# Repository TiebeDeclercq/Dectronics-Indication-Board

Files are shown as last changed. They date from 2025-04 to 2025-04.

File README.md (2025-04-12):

# DECTRONICS INDICATION BOARD

The LED PCB is a versatile lighting interface board designed to connect standard LEDs and addressable WS2812B RGB LEDs to systems via FCP connectors or pin headers. It provides flexible soldering options to choose which connection option you want to use.
## Overview

This PCB serves as a lighting expansion board that can be integrated with various systems through standardized connectors. It features both power indicator LEDs and a chain of WS2812B addressable RGB LEDs, making it suitable for status indication, ambient lighting, and visual feedback in electronic projects.

## Features

- **Power/Status LEDs**: 4 individual LEDs with current-limiting resistors
- **WS2812B Support**: Chain of 6 addressable RGB LEDs
- **Dual FCP Connectors**: Front and back connection options
- **Header Connectors**: Standard 2.54mm pin headers for breadboard compatibility
- **Flexible Soldering**: Multiple connection points for different configurations
- **Mounting Holes**: Two mounting holes for secure installation
## Hardware Schematic
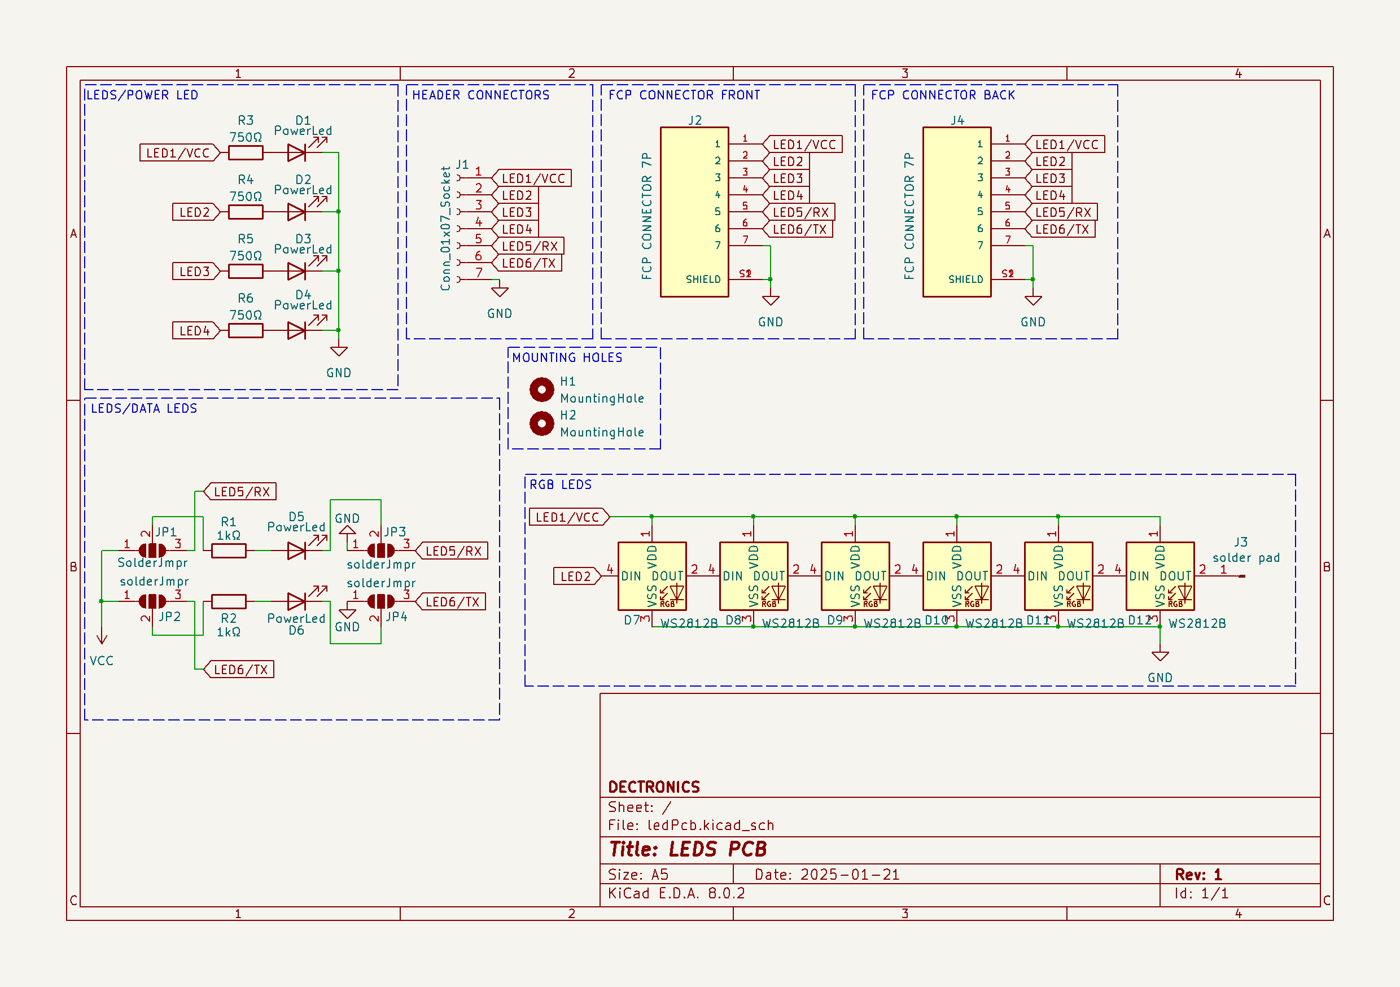
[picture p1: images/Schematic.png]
Indication board Schematic

## Assembled PCB
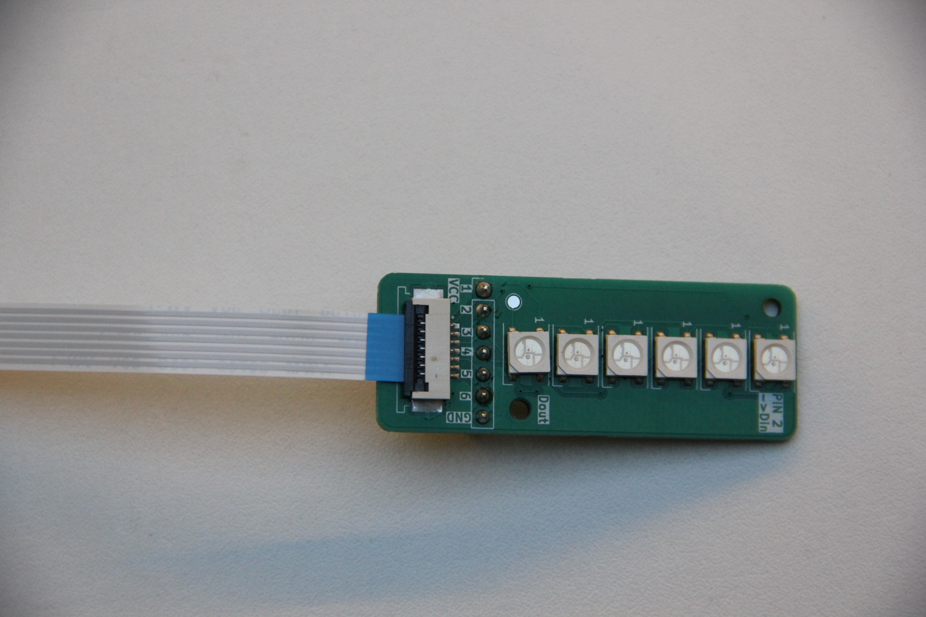
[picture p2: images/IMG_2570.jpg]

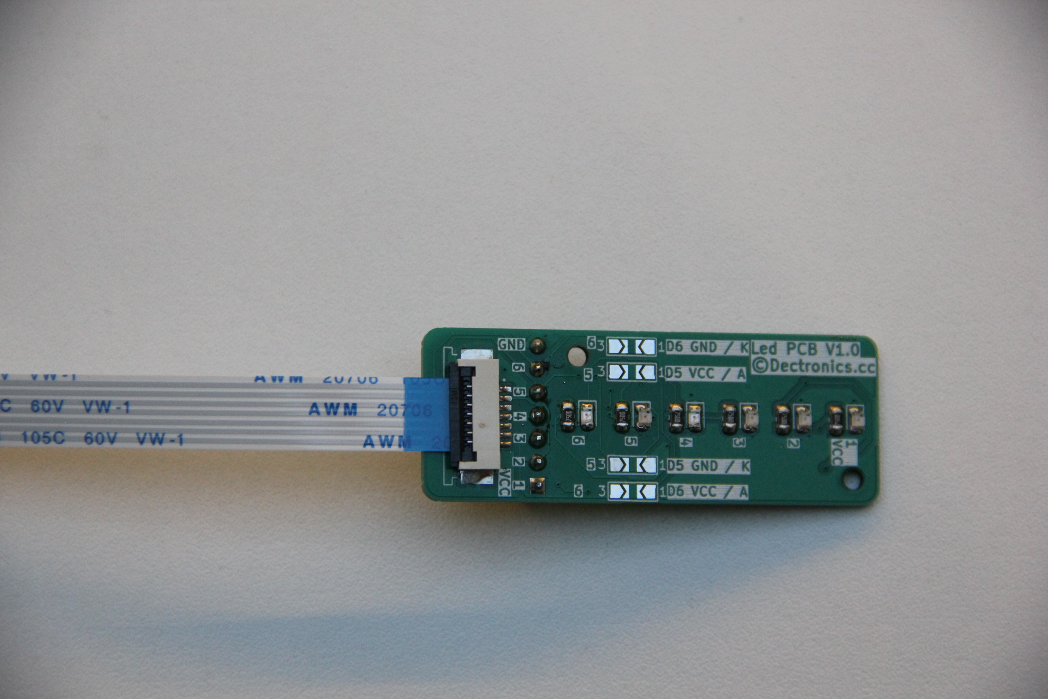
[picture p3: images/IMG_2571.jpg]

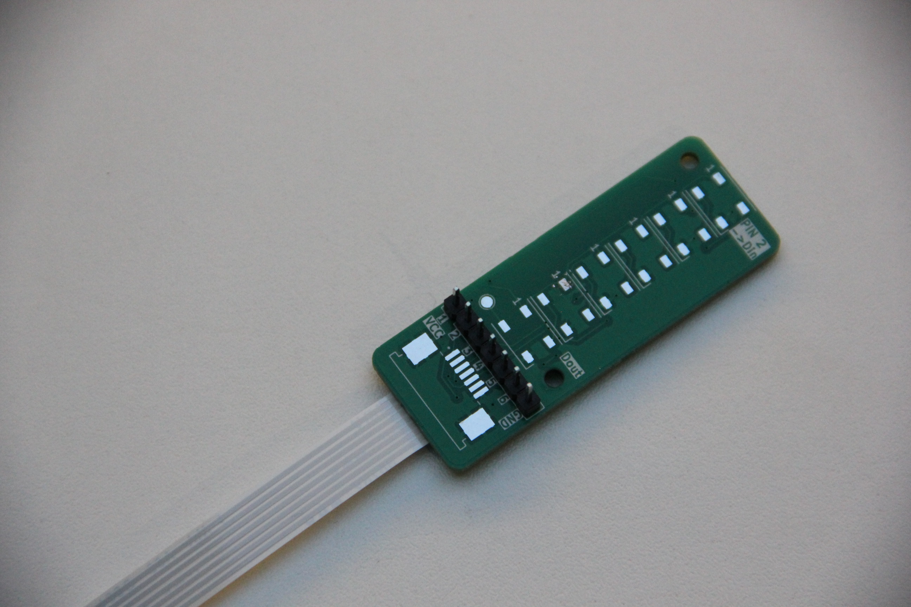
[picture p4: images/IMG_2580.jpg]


## Connector Pinout
### FCP Connector (J2/J4)

| Pin | Function |
| --- | --- |
| 1 | LED1/VCC |
| 2 | LED2 |
| 3 | LED3 |
| 4 | LED4 |
| 5 | LED5/RX  |
| 6 | LED6/TX  |
| 7 | GND |

### Header Connector (J1)

|Pin|Function|
|---|---|
|1|LED1/VCC|
|2|LED2|
|3|LED3|
|4|LED4|
|5|LED5/RX|
|6|LED6/TX|
|7|GND|

## Soldering Options

The PCB includes multiple solder jumpers (JP1-JP4) that allow you to configure the connections based on your specific requirements:

- **JP1/JP3**: Via these jumpers you can configure if you want to use it as an adressable led or to see the rx progress on the led
- **JP2/JP4**: Via these jumpers you can configure if you want to use it as an adressable led or to see the tx progress on the led

### Soldering Configurations:

You can choose to solder different components depending on your needs:

1. **Status LEDS**: Solder R3-R6 and D1-D4 for basic power/status indication
2. **RGB LEDS**: Solder the WS2812B LEDs (D7-D12) and appropriate jumpers
## Mounting

The PCB includes two mounting holes (H1 and H2) for secure installation using M3 screws.

## Usage Examples

### Status Indication

Use the individual LEDs (D1-D4) to indicate system status, power levels, or operational modes.

### Ambient Lighting

Program the WS2812B LEDs for decorative lighting effects, color-coded status information, or animations.

### Visual Feedback

Create visual feedback systems using the addressable RGB LEDs to indicate process states, alert conditions, or data visualization.
## Compatibility

This LED PCB is designed to work with:

- Systems using FCP connector standard
- Breadboard-compatible systems via pin headers
- Any microcontroller capable of driving WS2812B LEDs

© DECTRONICS

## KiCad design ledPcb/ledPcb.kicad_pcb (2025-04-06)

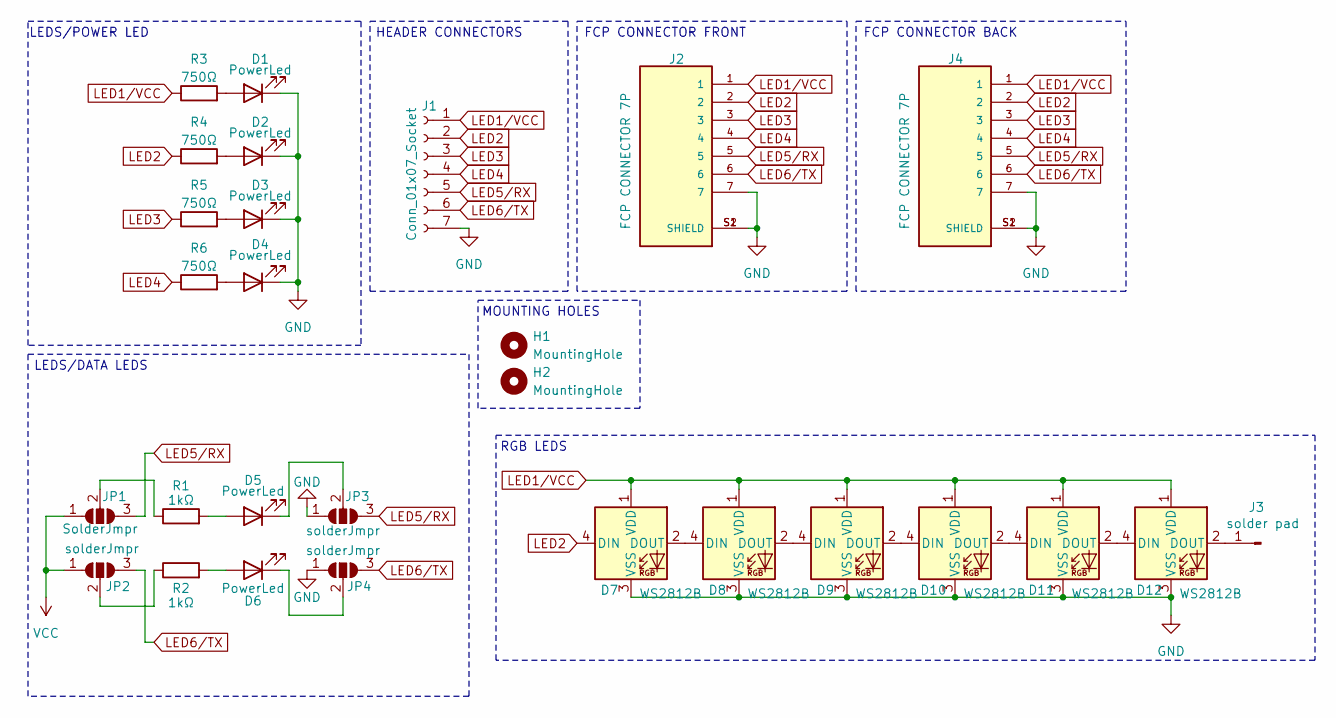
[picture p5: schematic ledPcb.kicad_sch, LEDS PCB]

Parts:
D1, D2, D3, D4, D5, D6: PowerLed; LED_0805_2012Metric
D7, D8, D9, D10, D11, D12: WS2812B; LED_WS2812B_PLCC4_5.0x5.0mm_P3.2mm
H1, H2: MountingHole; MountingHole_2.2mm_M2
J1: Conn_01x07_Socket; PinHeader_1x07_P2.54mm_Vertical
J2, J4: FCP CONNECTOR 7P; FCP7P; PARTREV A4
J3: solder pad; TestPoint_Pad_D1.5mm
JP1: SolderJmpr; SolderJumper-3_P2.0mm_Open_TrianglePad1.0x1.5mm_NumberLabels
JP2, JP3, JP4: solderJmpr; SolderJumper-3_P2.0mm_Open_TrianglePad1.0x1.5mm_NumberLabels
R1, R2: 1kΩ; R_0805_2012Metric_Pad1.20x1.40mm_HandSolder
R3, R4, R5, R6: 750Ω; R_0805_2012Metric_Pad1.20x1.40mm_HandSolder

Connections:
GND: D1.1 (K), D2.1 (K), D3.1 (K), D4.1 (K), D7.3 (VSS), D8.3 (VSS), D9.3 (VSS), D10.3 (VSS), D11.3 (VSS), D12.3 (VSS), J1.7, J2.7, J2.S1 (SHIELD), J2.S2 (SHIELD), J4.7, J4.S1 (SHIELD), J4.S2 (SHIELD), JP3.1 (A), JP4.1 (A)
LED1/VCC: D7.1 (VDD), D8.1 (VDD), D9.1 (VDD), D10.1 (VDD), D11.1 (VDD), D12.1 (VDD), J1.1, J2.1, J4.1, R3.1
LED2: D7.4 (DIN), J1.2, J2.2, J4.2, R4.1
LED3: J1.3, J2.3, J4.3, R5.1
LED4: J1.4, J2.4, J4.4, R6.1
LED5/RX: J1.5, J2.5, J4.5, JP1.3 (B), JP3.3 (B)
LED6/TX: J1.6, J2.6, J4.6, JP2.3 (B), JP4.3 (B)
unnamed: D1.2 (A), R3.2
unnamed: D2.2 (A), R4.2
unnamed: D3.2 (A), R5.2
unnamed: D4.2 (A), R6.2
unnamed: D5.2 (A), R1.2
unnamed: D5.1 (K), JP3.2 (C)
unnamed: D6.2 (A), R2.2
unnamed: D6.1 (K), JP4.2 (C)
unnamed: D7.2 (DOUT), D8.4 (DIN)
unnamed: D8.2 (DOUT), D9.4 (DIN)
unnamed: D9.2 (DOUT), D10.4 (DIN)
unnamed: D10.2 (DOUT), D11.4 (DIN)
unnamed: D11.2 (DOUT), D12.4 (DIN)
unnamed: D12.2 (DOUT), J3.1
unnamed: JP1.2 (C), R1.1
unnamed: JP2.2 (C), R2.1
VCC: JP1.1 (A), JP2.1 (A)

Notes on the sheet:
LEDS/POWER LED
LEDS/DATA LEDS
RGB LEDS
FCP CONNECTOR BACK
MOUNTING HOLES
FCP CONNECTOR FRONT
HEADER CONNECTORS

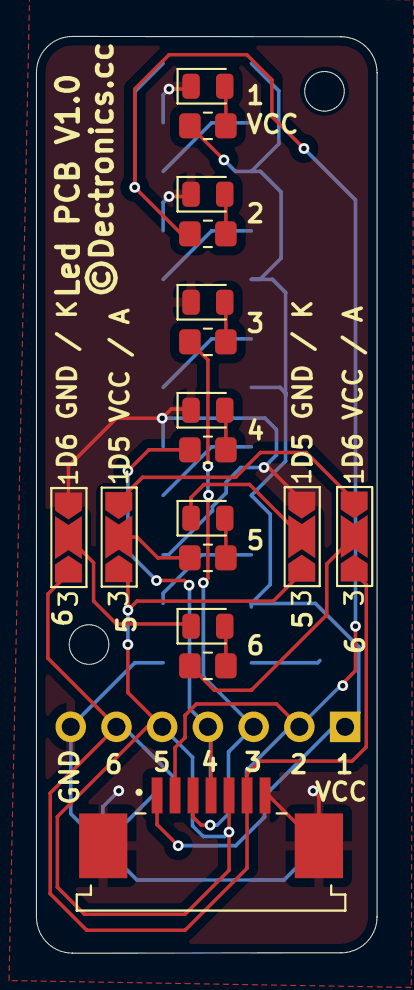
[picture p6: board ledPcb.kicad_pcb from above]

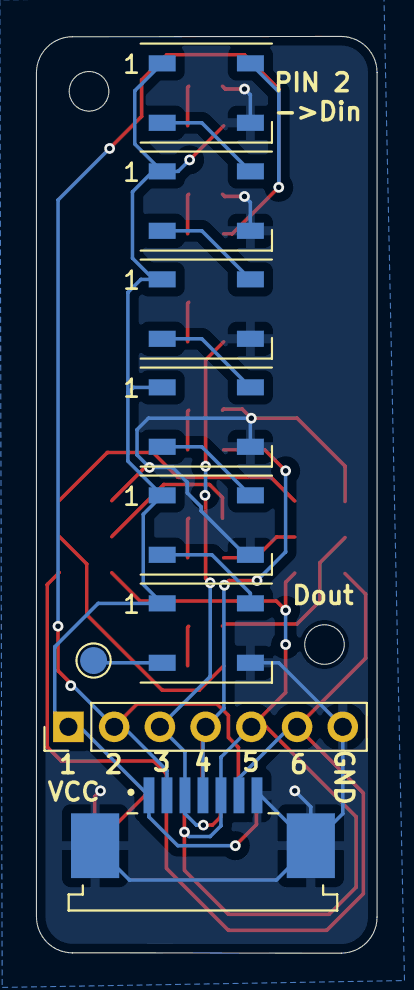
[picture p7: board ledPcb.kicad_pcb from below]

Board: 2 copper layers, 18.9 x 50.9 mm, 28 parts (9 on the bottom side), 24 nets.

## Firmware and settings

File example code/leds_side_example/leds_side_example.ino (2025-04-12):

// Pin definitions for LED control
#define LED1_PIN        2    // LED1
#define LED2_PIN        0    // LED2
#define LED3_PIN        4    // LED3

// Optional, only if you have configured the correct solder pads
#define LED4_PIN     16    // LED5/RX data indicator
#define LED5_PIN     17    // LED6/TX data indicator

void setup() {
  pinMode(LED1_PIN, OUTPUT);
  pinMode(LED2_PIN, OUTPUT);
  pinMode(LED3_PIN, OUTPUT);

  pinMode(LED4_PIN, OUTPUT);
  pinMode(LED5_PIN, OUTPUT);
}

void loop() {
  digitalWrite(LED1_PIN, HIGH);
  digitalWrite(LED3_PIN, LOW);
  delay(200);
  digitalWrite(LED1_PIN, LOW);
  digitalWrite(LED2_PIN, HIGH);
  delay(200);
  digitalWrite(LED2_PIN, LOW);
  digitalWrite(LED3_PIN, HIGH);
  delay(200);
}

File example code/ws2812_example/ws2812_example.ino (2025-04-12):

#include <FastLED.h>

// WS2812B RGB LEDs configuratie
#define RGB_DATA_PIN    5    // Data pin verbonden met WS2812B DIN
#define NUM_LEDS        6    // Aantal WS2812B LEDs in de keten
#define BRIGHTNESS     50    // Standaard helderheid (0-255)
#define LED_TYPE   WS2812B
#define COLOR_ORDER    GRB

// Definieer de LED array
CRGB leds[NUM_LEDS];

// Variabelen voor animaties
uint8_t gHue = 0;  // roterende "basis kleur" voor regenboog effecten
uint8_t currentPattern = 0;
uint8_t numPatterns = 6;  // Totaal aantal patronen

// Variabelen voor animaties (om scope-problemen te voorkomen)
uint8_t pos = 0;       // Voor bewegende kleur
uint8_t posDot = 0;    // Voor stippel-animatie
uint8_t pos1 = 0;      // Voor dubbele animatie
uint8_t pos2 = 0;      // Voor dubbele animatie
uint8_t brightness = 0;    // Voor pulserende animatie
uint8_t temperature = 0;   // Voor temperatuur animatie

// Timing variabelen
unsigned long previousMillis = 0;
unsigned long patternDuration = 10000;  // Tijd tussen patroonwisselingen (ms)

void setup() {
  // Initialiseer seriële communicatie voor debugging
  Serial.begin(115200);
  Serial.println("WS2812B RGB LED Controller");
  
  // Initialiseer WS2812B LEDs
  FastLED.addLeds<LED_TYPE, RGB_DATA_PIN, COLOR_ORDER>(leds, NUM_LEDS)
    .setCorrection(TypicalLEDStrip)
    .setDither(BRIGHTNESS < 255);
  FastLED.setBrightness(BRIGHTNESS);
  
  // Alle LEDs uitzetten
  FastLED.clear();
  FastLED.show();
  
  // Start met een testsequentie
  startupSequence();
}

void loop() {
  // Controleer of het tijd is om van patroon te veranderen
  unsigned long currentMillis = millis();
  if (currentMillis - previousMillis >= patternDuration) {
    previousMillis = currentMillis;
    currentPattern = (currentPattern + 1) % numPatterns;
    Serial.print("Verandering naar patroon: ");
    Serial.println(currentPattern);
  }
  
  // Update de RGB LEDs op basis van het huidige patroon
  updateRgbPattern(currentPattern);
  
  // Laat de FastLED show functie draaien
  FastLED.show();
  
  // Voeg een kleine vertraging toe om animaties soepel te houden
  FastLED.delay(15);
  
  // Update de kleur die gebruikt wordt voor sommige animaties
  EVERY_N_MILLISECONDS(20) { gHue++; }
}

// Verschillende RGB LED patronen
void updateRgbPattern(uint8_t patternNumber) {
  switch (patternNumber) {
    case 0:
      // Regenboog
      fill_rainbow(leds, NUM_LEDS, gHue, 7);
      break;
      
    case 1:
      // Kleur verschuiven (blauw beweegt over de strip)
      fadeToBlackBy(leds, NUM_LEDS, 20);
      EVERY_N_MILLISECONDS(50) {
        pos = (pos + 1) % (NUM_LEDS + 5);
      }
      if (pos < NUM_LEDS) {
        leds[pos] = CRGB::Blue;
      }
      break;
      
    case 2:
      // Pulserende rode kleur
      brightness = beatsin8(60, 20, 255);
      fill_solid(leds, NUM_LEDS, CHSV(0, 255, brightness));
      break;
      
    case 3:
      // Bewegende regenboog stippen
      fadeToBlackBy(leds, NUM_LEDS, 20);
      posDot = beatsin16(13, 0, NUM_LEDS - 1);
      leds[posDot] += CHSV(gHue, 255, 192);
      break;
      
    case 4:
      // Twee tegengestelde kleurrotaties
      fadeToBlackBy(leds, NUM_LEDS, 20);
      pos1 = beatsin16(10, 0, NUM_LEDS - 1);
      pos2 = beatsin16(15, 0, NUM_LEDS - 1);
      leds[pos1] += CHSV(gHue, 200, 255);
      leds[pos2] += CHSV(gHue + 128, 200, 255);
      break;
      
    case 5:
      // Kleurtemperatuur veranderingen
      temperature = beatsin8(10, 0, 255);
      fill_solid(leds, NUM_LEDS, HeatColor(temperature));
      break;
  }
}

// Opstartsequentie om te controleren of alle RGB LEDs werken
void startupSequence() {
  // RGB LED opstart test - witte flits
  fill_solid(leds, NUM_LEDS, CRGB::White);
  FastLED.show();
  delay(500);
  FastLED.clear();
  FastLED.show();
  delay(500);
  
  // RGB LED kleurentest
  // Rood
  fill_solid(leds, NUM_LEDS, CRGB::Red);
  FastLED.show();
  delay(500);
  
  // Groen
  fill_solid(leds, NUM_LEDS, CRGB::Green);
  FastLED.show();
  delay(500);
  
  // Blauw
  fill_solid(leds, NUM_LEDS, CRGB::Blue);
  FastLED.show();
  delay(500);
  
  // Alle LEDs uit
  FastLED.clear();
  FastLED.show();
  
  Serial.println("Opstartsequentie voltooid");
}

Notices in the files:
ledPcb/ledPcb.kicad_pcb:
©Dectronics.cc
